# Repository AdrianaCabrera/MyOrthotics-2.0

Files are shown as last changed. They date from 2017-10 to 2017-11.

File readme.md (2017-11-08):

# MyOrthotics 2.0 Workshop

MyOrthotics 2.0 is a new version of the Fab Academy final project (MyOrthotics), developed by Adriana Cabrera in 2016 for cases of semi paralysis. 

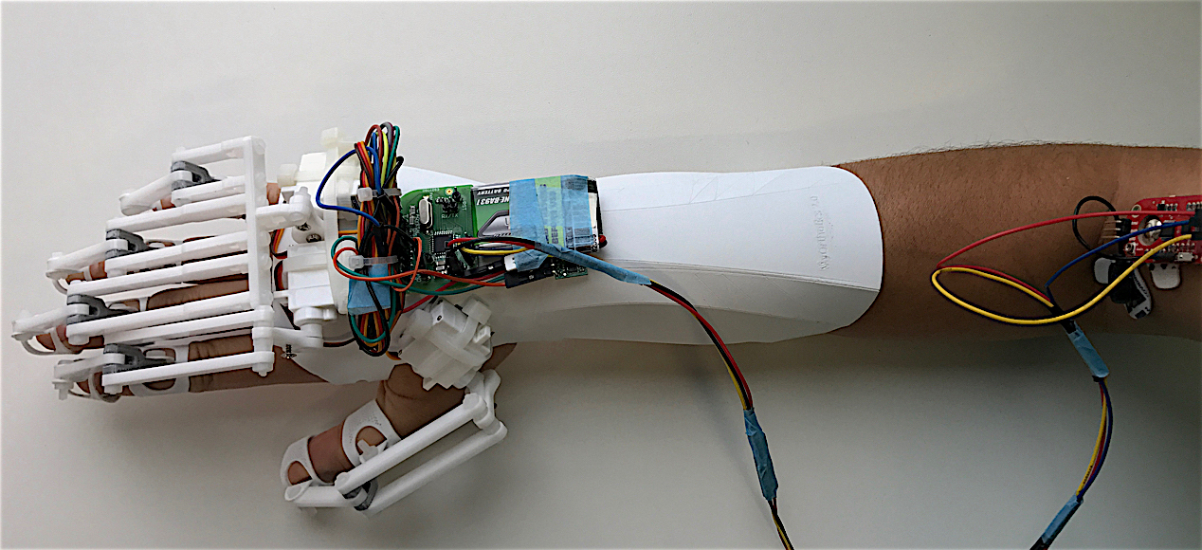
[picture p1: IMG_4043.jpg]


This version is based on cutting and its purpose is to explore rapid construction for orthotics for first aid cases or temporary use.
The first version of this orthotic workshop was realized in the Fab Lab Kamp-Lintfort Hochschule Rhein Waal for the course of Biomechanics and Biomaterial and for the class of Prof. William Megill. 

The changes of the microcontroller board were designed for the workshop Hands on assistive devices (MyOrthotics 2.0) realized in the international Fab Lab Conference in Santiago de Chile. 

In the repository you can find the template of the splint for men and women to introduction of the topic. For optimal fitting, 3D scanning the patient's arm and hand is recommended. 

1. 3D Scanning
   1. Repairing Mesh Remake
   2. 360 Fusion
   3. Exact Flat 
   4. Folding patterns 
1. Cutting
   1. Illustrator, Rhinoceros, preparing the file
   2. Belt test measurements on your body
   3. Cutting phallanges

1. Electronic
   1. Introduction to soldering 
   2. MyOrthotics SKu Board
   3. Voltage regulator
   4. MyOWare Sensor

1. 3D printing on the surface 

1. Assembly 
   1. Motors 
   2. Exoskeleton 
   3. Phalanges 
1. Wiring

Check in detail the documentation of the project in the following PDF
[MyOrthotics 2.0 Workshop manual](https://github.com/AdrianaCabrera/MyOrthotics-2.0/blob/master/MyOrthotics%20Manual.pdf))

And here you can check the required components in the Bill of Material table:

# Materials

* 0.8 mm x 30mm x30mm Polypropylen-Folie
* 10 Nylon Screws M3 
* 10 Nylon nuts M3
* 3 Servo Motors Torque (no less that 1,5 gr. And 1:60 mm/ s)
* MyoWare Muscle Sensor
* 1 Microcontroller Board MyOrthotics Sku (based on satshakit micro [https://github.com/satshas/satshakit/tree/master/docs/satshakit_micro]())
* Jumper wires
* 1 Battery 3.7 V 750mah 1S 3
* 1 Pololu 5V Step-Up 
* 15 cm Plexiglas or MDF

[Bill of Material](https://docs.google.com/spreadsheets/d/199VWikn73-JOAMEcc2uPSlAMuQEjKREj8A_Vey5oZjk/edit?usp=sharing))

## Authors

* **Adriana Cabrera**
* Contact

* [adriana.cabrera.g@gmail.com]()
* [adriana.cabrera@hochschule-rhein-waal.de]()
* [linkedin](https://www.linkedin.com/in/adrianacabrerag/) 

## Thanks
* [3D-Kompetenzzentrum Niederrhein](https://www.3dzentrum-niederrhein.de/)
* [Fablab Kamp-Lintfort]()
* [Hochschule Rhein-Waal]()
* Friedrich-Heinrich-Allee 25, 47475 Kamp-Lintfort, Germany
* fablab@hochschule-rhein-waal.de 

## License

This work is licensed under the terms of Attribution-NonCommercial-ShareAlike 4.0 International (CC BY-NC-SA 4.0).
Source code is licensed under the terms of the GNU Lesser General Public License v2.1 (LGPL). Adriana Cabrera 2016

## Disclaimer

This hardware/software is provided "as is", and you use the hardware/software at your own risk. Under no circumstances shall any author be liable for direct, indirect, special, incidental, or consequential damages resulting from the use, misuse, or inability to use this hardware/software.

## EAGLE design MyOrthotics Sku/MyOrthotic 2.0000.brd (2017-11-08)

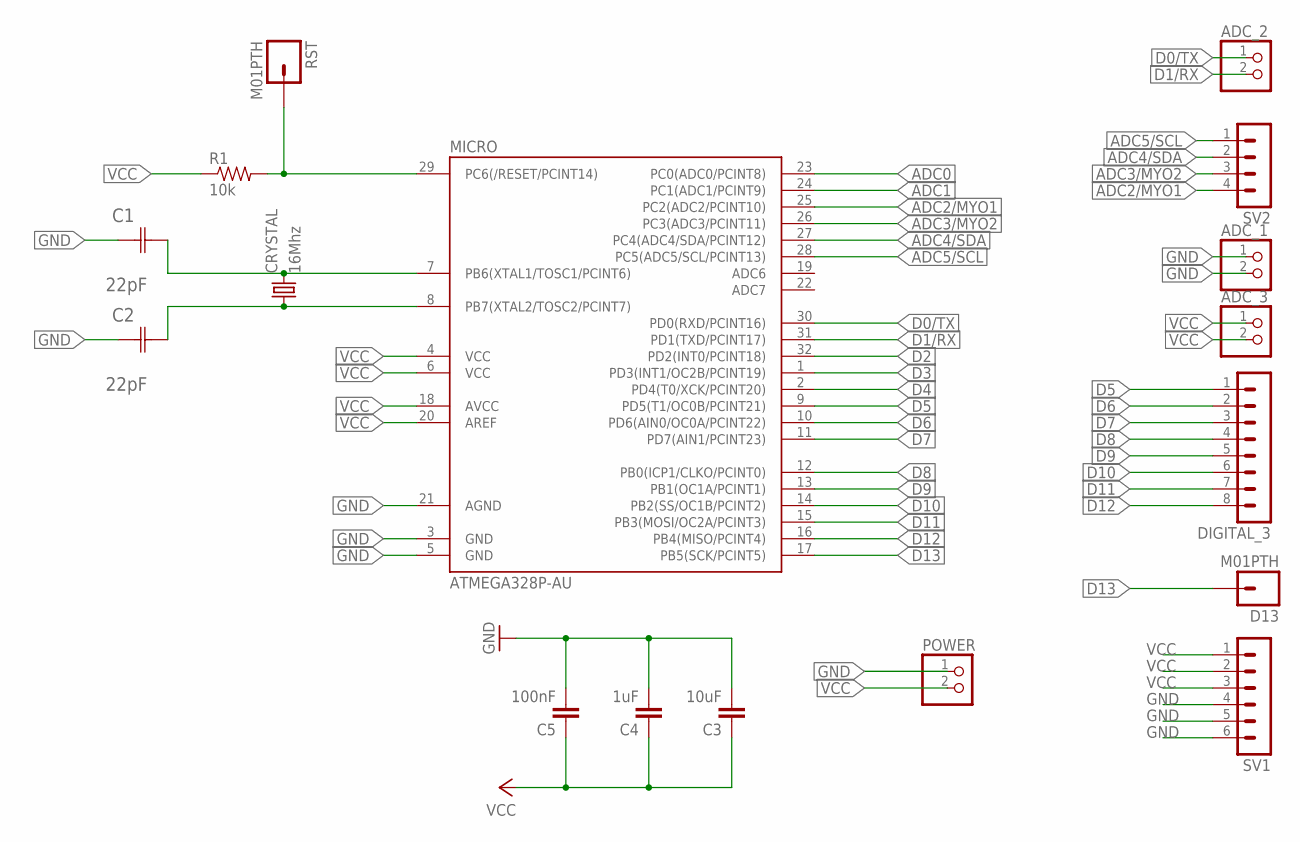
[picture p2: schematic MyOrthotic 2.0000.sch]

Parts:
ADC_1, ADC_2, ADC_3: PINHD-1X2; 1X02
C1, C2: 22pF; CAPC3216X178N
C3: 10uF; 1206
C4: 1uF; 1206
C5: 100nF; 1206
CRYSTAL: 16Mhz; CSM-7X-DU
D13: M01PTH; 1X01
DIGITAL_3: MA08-1
MICRO: ATMEGA328P-AU; TQFP32-08
POWER: PINHD-1X2; 1X02
R1: 10k; 1206
RST: M01PTH; 1X01
SV1: MA06-1
SV2: MA04-1

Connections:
ADC0: MICRO.23 (PC0(ADC0/PCINT8))
ADC1: MICRO.24 (PC1(ADC1/PCINT9))
ADC2/MYO1: MICRO.25 (PC2(ADC2/PCINT10)), SV2.4
ADC3/MYO2: MICRO.26 (PC3(ADC3/PCINT11)), SV2.3
ADC4/SDA: MICRO.27 (PC4(ADC4/SDA/PCINT12)), SV2.2
ADC5/SCL: MICRO.28 (PC5(ADC5/SCL/PCINT13)), SV2.1
D0/TX: ADC_2.1, MICRO.30 (PD0(RXD/PCINT16))
D1/RX: ADC_2.2, MICRO.31 (PD1(TXD/PCINT17))
D2: MICRO.32 (PD2(INT0/PCINT18))
D3: MICRO.1 (PD3(INT1/OC2B/PCINT19))
D4: MICRO.2 (PD4(T0/XCK/PCINT20))
D5: DIGITAL_3.1, MICRO.9 (PD5(T1/OC0B/PCINT21))
D6: DIGITAL_3.2, MICRO.10 (PD6(AIN0/OC0A/PCINT22))
D7: DIGITAL_3.3, MICRO.11 (PD7(AIN1/PCINT23))
D8: DIGITAL_3.4, MICRO.12 (PB0(ICP1/CLKO/PCINT0))
D9: DIGITAL_3.5, MICRO.13 (PB1(OC1A/PCINT1))
D10: DIGITAL_3.6, MICRO.14 (PB2(SS/OC1B/PCINT2))
D11: DIGITAL_3.7, MICRO.15 (PB3(MOSI/OC2A/PCINT3))
D12: DIGITAL_3.8, MICRO.16 (PB4(MISO/PCINT4))
D13: D13.1, MICRO.17 (PB5(SCK/PCINT5))
GND: ADC_1.1, ADC_1.2, C1.1 (C1), C2.1 (C1), C3.2, C4.2, C5.2, MICRO.3 (GND), MICRO.5 (GND), MICRO.21 (AGND), POWER.1, SV1.4, SV1.5, SV1.6
unnamed: C1.2 (C2), CRYSTAL.2, MICRO.7 (PB6(XTAL1/TOSC1/PCINT6))
unnamed: MICRO.29 (PC6(/RESET/PCINT14)), R1.2, RST.1
unnamed: C2.2 (C2), CRYSTAL.1, MICRO.8 (PB7(XTAL2/TOSC2/PCINT7))
VCC: ADC_3.1, ADC_3.2, C3.1, C4.1, C5.1, MICRO.4 (VCC), MICRO.6 (VCC), MICRO.18 (AVCC), MICRO.20 (AREF), POWER.2, R1.1, SV1.1, SV1.2, SV1.3

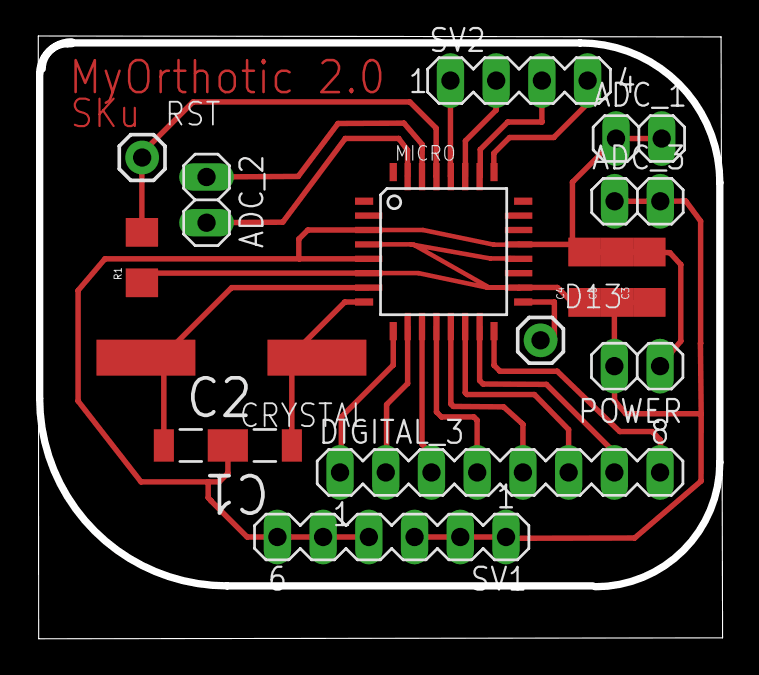
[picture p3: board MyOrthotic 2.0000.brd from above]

Board: 2 copper layers, 38.0 x 33.5 mm, 17 parts (0 on the bottom side), 20 nets.

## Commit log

2017-10-09 MyOrthotics 2.0
    MyOrthotics 2.0
    Bio inspired structures and human interaction are infinite source of
    inspiration applied in wearables, rehabilitation, prosthetics and other
    assistive devices.The process of making assistive devices has until
    recent years been a long and expensive individualized process,
    requiring detailed development and bespoke labor by physical therapists
    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
2017-11-08 new repository
    new repository
    [MyOrthotic 2.0000.brd, MyOrthotic 2.0000.sch]

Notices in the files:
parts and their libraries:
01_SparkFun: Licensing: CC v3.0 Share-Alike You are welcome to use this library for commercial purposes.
